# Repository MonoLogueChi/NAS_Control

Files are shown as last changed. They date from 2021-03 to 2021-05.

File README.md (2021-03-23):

## 项目介绍

这是一个自制 NAS 的项目，包括机箱和一部分控制程序。

初步版本为一个 6 盘位 NAS 机箱，外壳 270\*210\*330 ，最大支持 ATX 主板，支持半高 PCIE 卡，支持 FLEX 电源。

硬盘垂直放置，垂直风道，正压散热，散热和防尘效果杠杠的。

风扇根据温度探头自动运行，支持自动调节和手动调节。

使用 arduino 控制 NAS 的行为，硬盘分批启动，防止因电流过大造成启动失败。

## 仓库介绍

本仓库主要有以下几部分构成

### 图纸

> 图纸部分尚未完成

机箱图纸，整个机箱使用 5mm 亚克力板切割，建议使用黑色或者骚红。

装配表待添加。

### PCB 板

> 已完成，尚未验证

主要是启动行为的控制部分。

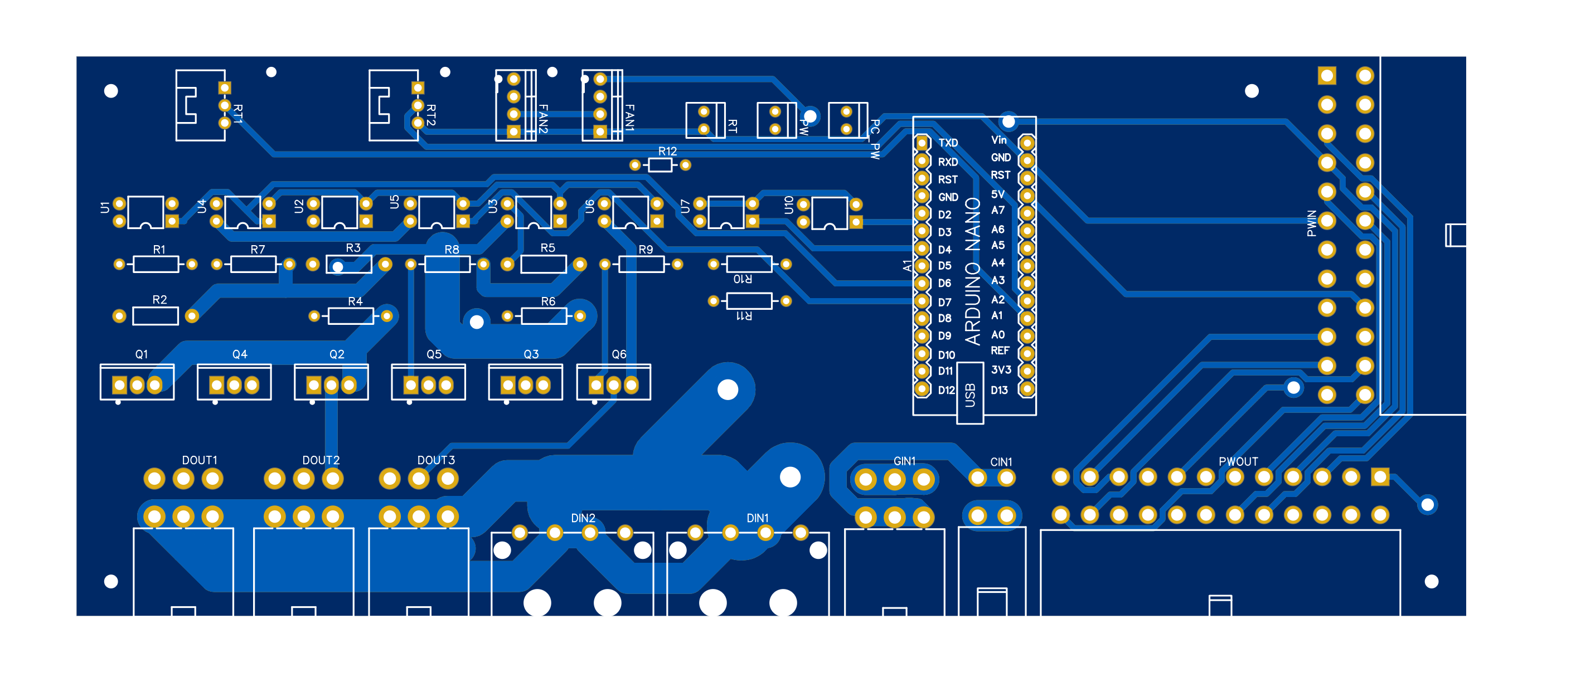
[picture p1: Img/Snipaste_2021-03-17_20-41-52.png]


注：PCB 板非实时渲染，以图纸为准。

### 控制程序

> 已完成，尚未验证

使用 Arduino 控制 NAS 的启动行为，实现一系列高级功能。

## 特点

- 6 盘位 NAS 机箱
- 最大支持 ATX 主板，兼容性好
- 支持半高 PCIE 卡(不支持全高)
- 多 PCIE 插槽可用，可同时插 SATA 扩展卡和万兆网卡
- 硬盘分批启动
- 自动或手动调整机器风扇转速

## 计划中

- 8 盘位版本
- 可配置的上电自启功能
- 小型 UPS 功能

## 说明

目前这个项目尚未完成，在验证可行性之前请勿使用。

## QQ 群

说明：

QQ 群为定制讨论群，有一部分资料，还有打样的板子也可以在群里找到。

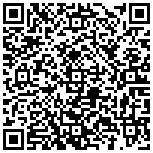
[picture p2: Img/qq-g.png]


972313206

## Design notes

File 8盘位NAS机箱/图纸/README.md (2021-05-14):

## 配件表

> 不完全

### 机箱

| 名称 | 规格 | 数量 | 备注 |
| :--- | :--- | :----- | :--- |
| 螺丝 | m3\*8 | 100 个 | 沉头 黑色 |
| 螺丝 | m3\*8 | 50 个  | 圆头或杯头 黑色 |
| 螺丝 | m3\*5 | 20 个  | 主板螺丝 |
| 铜柱 | m3\*7 | 20 个  | 双通 |
| 铜柱 | m3\*5 | 10 个  | 双通 |
| 垫片 | m3 | 10 个  | 纸垫片 0.5mm 厚 |
| 铝方 | 8\*15mm | 20cm | |
| 铝方 | 4\*15mm | 10cm | |

### 硬盘笼

| 名称 | 规格 | 数量  | 备注 |
| :--- | :----- | :---- | :--- |
| 硬盘笼 | | 2 个  | |
| 硬盘笼背板 | | 2 张  | 见 PCB 部分 |
| 螺丝 | m3\*4  | 50 个 | 圆头或杯头 黑色 |
| 铜柱 | m3\*15 | 12 个 | 双通 |

## 风扇

- 120 风扇 \* 1
- 80 风扇 \* 1

## 装配工具

1. 螺丝刀（对应上面的螺丝）
2. 电钻（需配有锪钻钻头，2.5mm/2.8mm，3.2/3.5mm 钻头），最好能使用台钻
3. 攻丝器（M3）

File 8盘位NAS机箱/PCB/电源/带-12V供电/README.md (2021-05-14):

# DC2ATX

基于 [KCORES-CSPS-to-ATX-Converter](https://github.com/KCORES/KCORES-CSPS-to-ATX-Converter) 修改的一个适合 NAS 使用的 DC-ATX 转接板。

相比原版，拥有以下特点

1. 重新定义了硬盘供电线序，并且拥有更多的硬盘供电接口
2. 增强 5V 输出能力
3. 增加 -12V 输出

## 说明

- 如用在其他项目，推荐使用双板电源，体积更小
- ATX 模组线与双板电源不通用
- 如不用 -12V 供电，-12V 部分可不焊接
- ~~如不需要修改，直接下载`Gerber`文件，直接下单 PCB 打样即可~~。

## 注意事项

- 注意事项参见 [KCORES-CSPS-to-ATX-Converter](https://github.com/KCORES/KCORES-CSPS-to-ATX-Converter)

## 预览

非实时，详情请以实际为准。

### 原理图

原理图

### 主电源板

主电源板顶面 主电源板底面

## BOM

非标准 BOM 表，方便购买

- `CSPS_64P_2.54MM` 某宝可搜 `FCI 64P 2.54MM`(质量较好，价格较高) 或 `SLOT 64P` `WingTAT 64P`(较便宜，低功率电源适用，注意看好间距)
- `5566连接器` 规格：`2*10P`(ATX 供电) `2*4P`(CPU/PCIE 供电) `2*2P`(硬盘供电)
- `IC座` DIP8
- `接线端子` 5.08MM 3P
- `排针` 2.54mm 3P 4P 配跳帽
- `电阻` 封装 1206，阻值 `22K` `3.3K` `2.67K`(高精度)
- `电容` 封装 1206，50V 100nF
- `钽电容` 封装 3528(B 型)，10V 47uF 或更高 3 个
- `二极管` 封装 DO-41，1N4001 或 1N4004
- `PW22ASAB` 海鲜市场拆机货，接 2.67K 输出 5V
- `Mini560` 5V 和 3.3V
- `M3螺丝` M3\*5 或 M3\*6
- `纸垫片` 纸垫片，M3 螺丝兼容
- `铜丝` 紫铜 1.5mm - 2.5mm，可直接买紫铜，也可将铜线剥开使用，使用前注意除锈。
- `DM25` 或 `B1212S-1W`(需焊接外围电路，50V 2.2uF 电容\*2，1.5-3KΩ 电阻 \*1)，二选一

## LICENSE

[kcores-license](../LICENSE)

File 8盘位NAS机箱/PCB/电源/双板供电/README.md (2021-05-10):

## DC2ATX

基于 [KCORES-CSPS-to-ATX-Converter](https://github.com/KCORES/KCORES-CSPS-to-ATX-Converter) 修改的一个适合 NAS 使用的 DC-ATX 转接板。

相比原版，拥有以下特点

1. 重新定义了硬盘供电线序，并且拥有更多的硬盘供电接口
2. 增强 5V 输出能力
3. 更小的体积

## 说明

- 如不需要修改，直接下载`Gerber`文件，直接下单 PCB 打样即可。

## 注意事项

- 注意事项参见 [KCORES-CSPS-to-ATX-Converter](https://github.com/KCORES/KCORES-CSPS-to-ATX-Converter)

## 预览

非实时，详情请以实际为准。

### 原理图

原理图

### 主电源板

主电源板顶面 主电源板底面

### 5V 供电板

5V供电板顶面 5V供电板底面

## BOOM

非标准 BOOM 表，方便购买

- `CSPS_64P_2.54MM` 某宝可搜 `FCI 64P 2.54MM`(质量较好，价格较高) 或 `SLOT 64P`(较便宜，低功率电源适用，注意看好间距)
- `5566连接器` 规格：`2\*10P`(ATX 供电) `2\*4P`(CPU/PCIE 供电) `2\*2P`(硬盘供电)
- `IC座` DIP8
- `接线端子` 5.08MM 3P
- `排针` 2.54mm 3P 4P 配跳帽
- `电阻` 封装 1206，阻值 `22K` `3.3K` `2.67K`(高精度)
- `电容` 封装 1206，50V 100nF
- `钽电容` 封装 3528(B 型)，10V 47uF 或更高 3 个
- `二极管` 封装 DO-41，1N4001 或 1N4004
- `PW22ASAB` 海鲜市场拆机货
- `Mini560` 5V 和 3.3V
- `PCB直角连接器` 见下方尺寸相关
- `M3螺丝` M3\*5 或 M3\*6
- `纸垫片` 纸垫片，M3 螺丝兼容
- `铜丝` 紫铜 2mm - 2.5mm，可直接买紫铜，也可将铜线剥开使用，使用前注意除锈。

### 尺寸

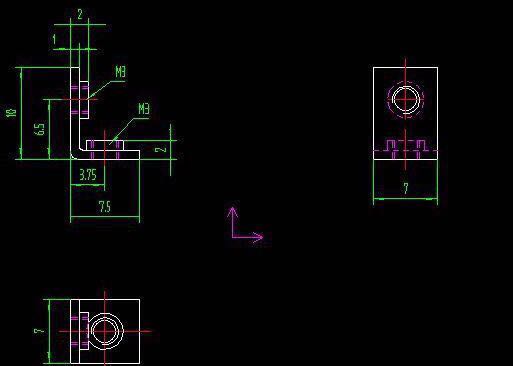
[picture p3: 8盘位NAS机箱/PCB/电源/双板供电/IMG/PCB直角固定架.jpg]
PCB直角固定架


## LICENSE

[kcores-license](../LICENSE)

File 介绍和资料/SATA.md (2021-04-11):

SATA 最关键的是 11 脚，可以通过 11 脚控制启动行为或者使用 11 脚指示读写状态。

- 11 脚接地，上电自动旋启；
- 用于读写指示时，11 脚接地表示有读写行为。

[HIGH SPEED SERIALIZED AT ATTACHMENT](sata_im.pdf)  
[SATA 介绍](https://en.wikipedia.org/wiki/Serial_ATA)  
[旋转 启动](https://en.wikipedia.org/wiki/Spin-up)

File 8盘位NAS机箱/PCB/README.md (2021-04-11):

介绍待更新，目前仍在测试中，请勿使用

## 感谢

电源部分参考：[KCORES-CSPS-to-ATX-Converter](https://github.com/KCORES/KCORES-CSPS-to-ATX-Converter)

## 备注

电源部分使用开源协议 [kcores-license](电源/LICENSE)。

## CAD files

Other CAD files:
8盘位NAS机箱/图纸/8盘位NAS机箱图纸.dwg
图纸/6盘位NAS图纸/6盘位NAS图纸.dwg
8盘位NAS机箱/图纸/NAS机箱.dwg

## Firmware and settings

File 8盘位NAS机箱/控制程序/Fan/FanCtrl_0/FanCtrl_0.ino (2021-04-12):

#include <PWM.h>

#define rt_pin1 14
#define rt_pin2 15
#define fan_pin1 3
#define fan_pin2 5

int32_t frequency = 25000;

int8_t fan_pwm1 = 0;
int8_t fan_pwm2 = 0;

int8_t pwm1 = 0;
int8_t pwm2 = 0;

int8_t min_pwm1 = 100;
int8_t min_pwm2 = 100;

void setup()
{
    InitTimers();
    SetPinFrequency(fan_pin1, frequency);
    SetPinFrequency(fan_pin2, frequency);

    pinMode(rt_pin1, INPUT);
    pinMode(rt_pin2, INPUT);
    pinMode(fan_pin1, OUTPUT);
    pinMode(fan_pin2, OUTPUT);

    delay(250000);
    set_fan();
}

void loop()
{
    read_temp();
    set_fan();
    delay(50000);
}

void set_fan()
{
    if (pwm1 != fan_pwm1)
    {
        fan_pwm1 = pwm1;
        pwmWrite(fan_pin1, fan_pwm1);
    }

    if (pwm2 != fan_pwm2)
    {
        fan_pwm2 = pwm2;
        pwmWrite(fan_pin2, fan_pwm2);
    }
}

void read_temp()
{
    float v_rt1 = analogRead(rt_pin1) / 204.6;
    float v_rt2 = analogRead(rt_pin2) / 204.6;

    pwm1 = floor((254 * (-20 * v_rt1 + 80)) / 50);
    pwm2 = floor((254 * (-20 * v_rt2 + 80)) / 50);

    if (pwm1 < min_pwm1)
    {
        pwm1 = 0;
    }
    else if (pwm1 > 254)
    {
        pwm1 = 254;
    }

    if (pwm2 < min_pwm2)
    {
        pwm2 = 0;
    }
    else if (pwm2 > 254)
    {
        pwm2 = 254;
    }
}

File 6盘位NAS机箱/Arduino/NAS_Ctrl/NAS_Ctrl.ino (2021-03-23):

#define TempPin 14   //A0 温度检测
#define TempR1Pin 15 //A1 调温电阻1
#define TempR2Pin 16 //A2 调温电阻2
#define PwPin 18     //A4 开关按钮
#define PwOkPin 19   //A5 检测电源是否开启

#define PCPwONPin 2 //D2 电脑开机键
#define FunPwnPin 3 //D3 风扇输出调速
#define PsONPin 4   //D4 电源启动开关
#define PwLedPin 5  //D5 电源LED灯
#define Disk1Pin 6  //D6 硬盘控制1
#define Disk2Pin 7  //D7 硬盘控制2
#define Disk3Pin 8  //D8 硬盘控制3

//0 关闭   1 开机，  2 正在开机
int IsOn = 0;

//风扇速度 0-255
int FunSpeed = 0;

//风扇调速曲线
const int TempMin = 0;
const int TempMax = 40;

//硬盘上电时间间隔
const int Ds = 6000;

void setup()
{
  //设置pinMode
  pinMode(TempPin, INPUT);
  pinMode(TempR1Pin, INPUT);
  pinMode(TempR2Pin, INPUT);
  pinMode(PwPin, INPUT);
  pinMode(PwOkPin, INPUT);

  pinMode(PCPwONPin, OUTPUT);
  pinMode(FunPwnPin, OUTPUT);
  pinMode(PsONPin, OUTPUT);
  pinMode(PwLedPin, OUTPUT);
  pinMode(Disk1Pin, OUTPUT);
  pinMode(Disk2Pin, OUTPUT);
  pinMode(Disk3Pin, OUTPUT);

  //初始化
  SetInit();

  //延迟15秒自动启动
  delay(15000);
  SetPcON();
}

void loop()
{
  if (!CheckPwOff())
  {
    //开机状态

    //调整风扇转速
    SetFunPwm(ReadTemp());

    //监听开关按键输入
    if (digitalRead(PwPin) == HIGH)
    {
      while (digitalRead(PwPin) == HIGH)
      {
        //当按下开关键时，给主板上电
        digitalWrite(PCPwONPin, HIGH);
        delay(200);
      }
      //释放开机键
      digitalWrite(PCPwONPin, LOW);
    }
  }
  else
  {
    //关机状态
    //监听开关按键输入
    if (digitalRead(PwPin) == HIGH)
    {
      while (digitalRead(PwPin) == HIGH)
      {
        //按下开机键无反应，直到释放
        delay(200);
      }

      //执行开机程序
      SetPcON();
    }
  }

  //每0.5s检测一次，所以必须按住开机键0.5s以上才有用
  delay(500);
  // put your main code here, to run repeatedly:
}

void SetInit()
{
  //将状态设置为关机
  IsOn = 0;

  //关闭LED
  digitalWrite(PwLedPin, LOW);

  // 关闭风扇
  SetFunPwm(0);

  //关闭电源
  ResetPw();

  //给磁盘开关高电平，高电平控制MOS管关闭
  digitalWrite(Disk1Pin, HIGH);
  delay(500);
  digitalWrite(Disk2Pin, HIGH);
  delay(500);
  digitalWrite(Disk3Pin, HIGH);
}

//开机程序
void SetPcON()
{
  IsOn = 2;

  //开启电源
  OpenPw();
  delay(500);

  //点亮LED灯
  digitalWrite(PwLedPin, HIGH);

  //开启风扇，测试全速状态
  SetFunPwm(255);
  delay(5000);
  //开启风扇，设置转速为大概一半
  SetFunPwm(100);
  delay(3000);

  //给主板开机
  digitalWrite(PCPwONPin, HIGH);
  delay(500);
  digitalWrite(PCPwONPin, LOW);

  //硬盘分批上电
  digitalWrite(Disk1Pin, LOW);
  delay(Ds);
  digitalWrite(Disk2Pin, LOW);
  delay(Ds);
  digitalWrite(Disk3Pin, LOW);
  delay(Ds);

  //关闭电源开关，并将状态设置为开机
  delay(5000);
  ResetPw();
  IsOn = 1;
}

//开启电源
void OpenPw()
{
  digitalWrite(PsONPin, HIGH);
}

//复位电源开关
void ResetPw()
{
  digitalWrite(PsONPin, LOW);
}

//检查是否已关机，开机 false，关机或其他状态 true
boolean CheckPwOff()
{
  if (IsOn == 0)
  {
    if (!CheckPwIsON())
    {
      return true;
    }
    else
    {
      // 关机状态，但是已接通电源，将状态设置为开机，并且返回false
      IsOn = 1;
      return false;
    }
  }

  if (IsOn == 1)
  {
    if (CheckPwIsON())
    {
      //开机状态，并且电源通电，返回false
      return false;
    }
    else
    {
      //设置状态为开机，但是电源没有输出，需要再次检测
      delay(500);
      //0.5s后再次检查是否有输出
      if (CheckPwIsON())
      {
        //有输出，直接返回false，表示是开机状态
        return false;
      }
      else
      {
        //没有输出，将状态设置为关机，并且重置状态
        SetInit();
        return true;
      }
    }
  }

  return true;
}

//检测电源是否已经通电，通电开机返回true，否则返回false
boolean CheckPwIsON()
{
  if (digitalRead(PwOkPin) == HIGH)
  {
    return true;
  }
  else
  {
    return false;
  }
}

//设置风扇转速
void SetFunPwm(int val)
{
  if (val == 0 && FunSpeed != 0)
  {
    FunSpeed = val;
    analogWrite(FunPwnPin, val);
  }
  else
  {
    if (abs(FunSpeed - val) > 3)
    {
      FunSpeed = val;
      analogWrite(FunPwnPin, val);
    }
  }
}

//读取温度，获得pwm值
//NTC B3950 10K 串联 8.06K电阻，测量热敏电阻两侧电压
int ReadTemp()
{
  int v = analogRead(TempPin);
  int Tmin = TempMin + int(analogRead(TempR1Pin)) * 7;
  int Tmax = TempMax + int(analogRead(TempR2Pin)) * 8;

  int k = int(255 / abs(Tmax - Tmin));
  int t = int(68 - (35 * v) / (5 - v));

  int p = int(k * (t - Tmin));

  if (p > 255)
  {
    return 255;
  }
  if (p < 0)
  {
    return 0;
  }
  return p;
}

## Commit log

2021-03-17 更新PCB
2021-03-17 更新图纸
    [6盘位NAS图纸.dwg]
2021-03-18 更新程序和PCB
2021-03-23 更新介绍
2021-03-23 更新程序
2021-05-10 更新电源部分
